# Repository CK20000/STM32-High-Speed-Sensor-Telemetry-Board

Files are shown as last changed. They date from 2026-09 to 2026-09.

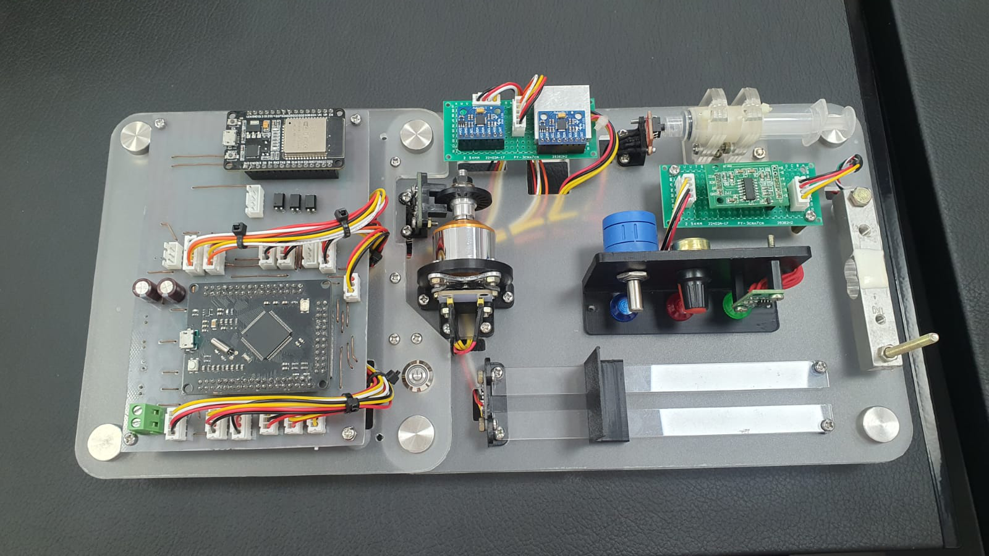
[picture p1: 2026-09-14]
hardware/images/WhatsApp Image 2026-08-07 at 17.46.26.jpeg

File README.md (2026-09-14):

# High-Speed Sensor Telemetry & Observer System Validation Board




[]()

## Project Overview
This repository contains the full hardware, firmware, and software stack for a custom sensor data acquisition board designed around the STM32F407VGT microcontroller. The system is engineered to capture, process, and stream multi-sensor data to validate a high-speed observer system framework. 

The architecture bridges custom PCB design, non-blocking C++ embedded firmware, and a modular Python dashboard to provide real-time telemetry, enabling precise tracking of stable motor rotation and load variables at high velocities.

WhatsApp Image 2026-08-07 at 17 46 26

---

## System Architecture

### 1. Hardware Integration (`/hardware`)
The custom-designed PCB acts as the central node for sensor fusion and motor state estimation. The board integrates the following components:
*   **MCU:** STM32F407VGT (ARM Cortex-M4).
*   **IMU:** MPU6050 (6-axis accelerometer and gyroscope) for inertial tracking.
*   **Magnetometer:** HMC5883L for heading reference.
*   **Time-of-Flight:** VL53L0X for precise distance measurements.
*   **Mechanical Sensors:** Direct interfaces for load cells and quadrature/optical encoders to track torque and rotation.
*   **Design Files:** KiCAD schematics, BOM, and mechanical CAD models are included.

### 2. Embedded Firmware (`/firmware`)
Written in C++, the firmware focuses on deterministic execution and high-speed data throughput:
*   **Non-Blocking I/O:** Ensures the sensor polling loop is not bottlenecked by communication delays.
*   **Telemetry Pipeline:** Constructs and streams an 84-byte binary payload containing timestamped sensor data and state variables.
*   **Virtual COM Port (VCP):** Utilizes USB CDC to achieve a stable 200Hz data transmission rate to the host PC. 

### 3. Telemetry Dashboard (`/software`)
A custom graphical interface developed in Python (PySide/PyQt) to visualize the observer system's performance in real-time.
*   **Serial Parsing (`comms.py`):** Efficiently unpacks the 84-byte binary stream at 200Hz.
*   **Real-Time Visualization (`gauges.py` / `ui/`):** Dynamic plotting of motor rotation, current readings, IMU data, and load metrics.
*   **Architecture:** Highly modular layout utilizing custom `.qss` stylesheets for a clean, industrial UI.

---

## Getting Started

### Prerequisites
*   **Hardware:** STM32 ST-LINK Utility or OpenOCD.
*   **Firmware:** ARM GCC Toolchain and CMake (or your preferred STM32 IDE like STM32CubeIDE).
*   **Software:** Python 3.8+ with `pyserial`, `PySide6` (or `PyQt6`), and `pyqtgraph`.

### Installation & Execution
1.  **Clone the Repository:**
    ```bash
    git clone [https://github.com/yourusername/stm32-telemetry-board.git](https://github.com/yourusername/stm32-telemetry-board.git)
    cd stm32-telemetry-board
    ```
2.  **Flash the Firmware:** 
    Compile the C++ source in the `/firmware` directory and flash the STM32F407 via ST-LINK.
3.  **Launch the Dashboard:**
    ```bash
    cd software
    pip install -r requirements.txt
    python main.py
    ```

---

## Current Development Status
*   [x] Custom PCB schematic and layout finalized.
*   [x] Virtual COM port pipeline validated (84-byte payload @ 200Hz).
*   [x] Python GUI rendering stable high-speed sensor plots.
*   [ ] Full observer system implementation in firmware (In Progress).

---

## License
This project is licensed under the MIT License - see the [LICENSE](LICENSE) file for details.

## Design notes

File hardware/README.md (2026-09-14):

Contains the KiCAD schematic, PCB layouts, component bill of materials, and mechanical CAD files for the sensor board.

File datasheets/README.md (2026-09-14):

Reference datasheets and documentation for components used on the board
(e.g. MPU6050, HMC5883L, VL53L0X, and other peripherals).

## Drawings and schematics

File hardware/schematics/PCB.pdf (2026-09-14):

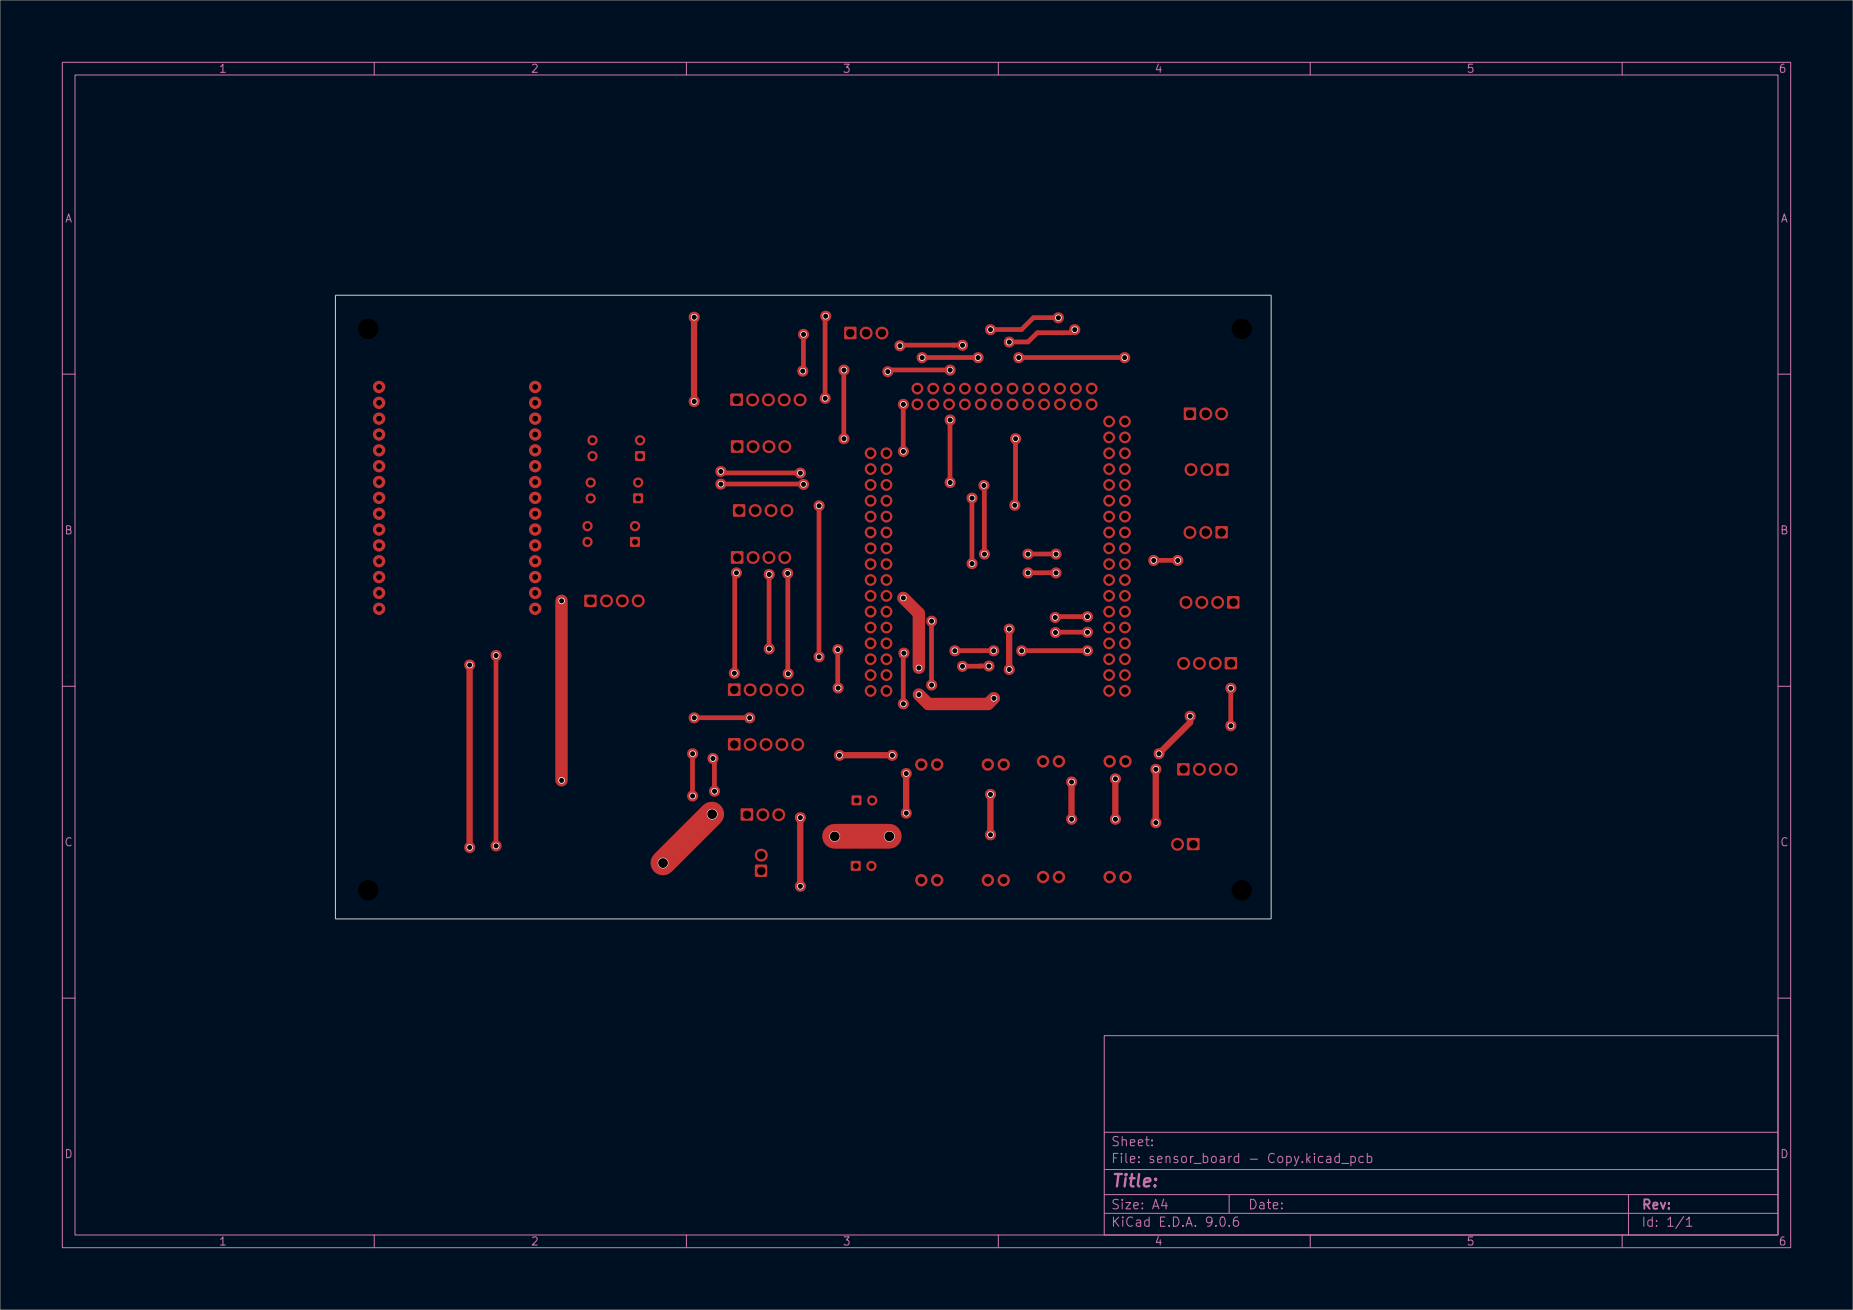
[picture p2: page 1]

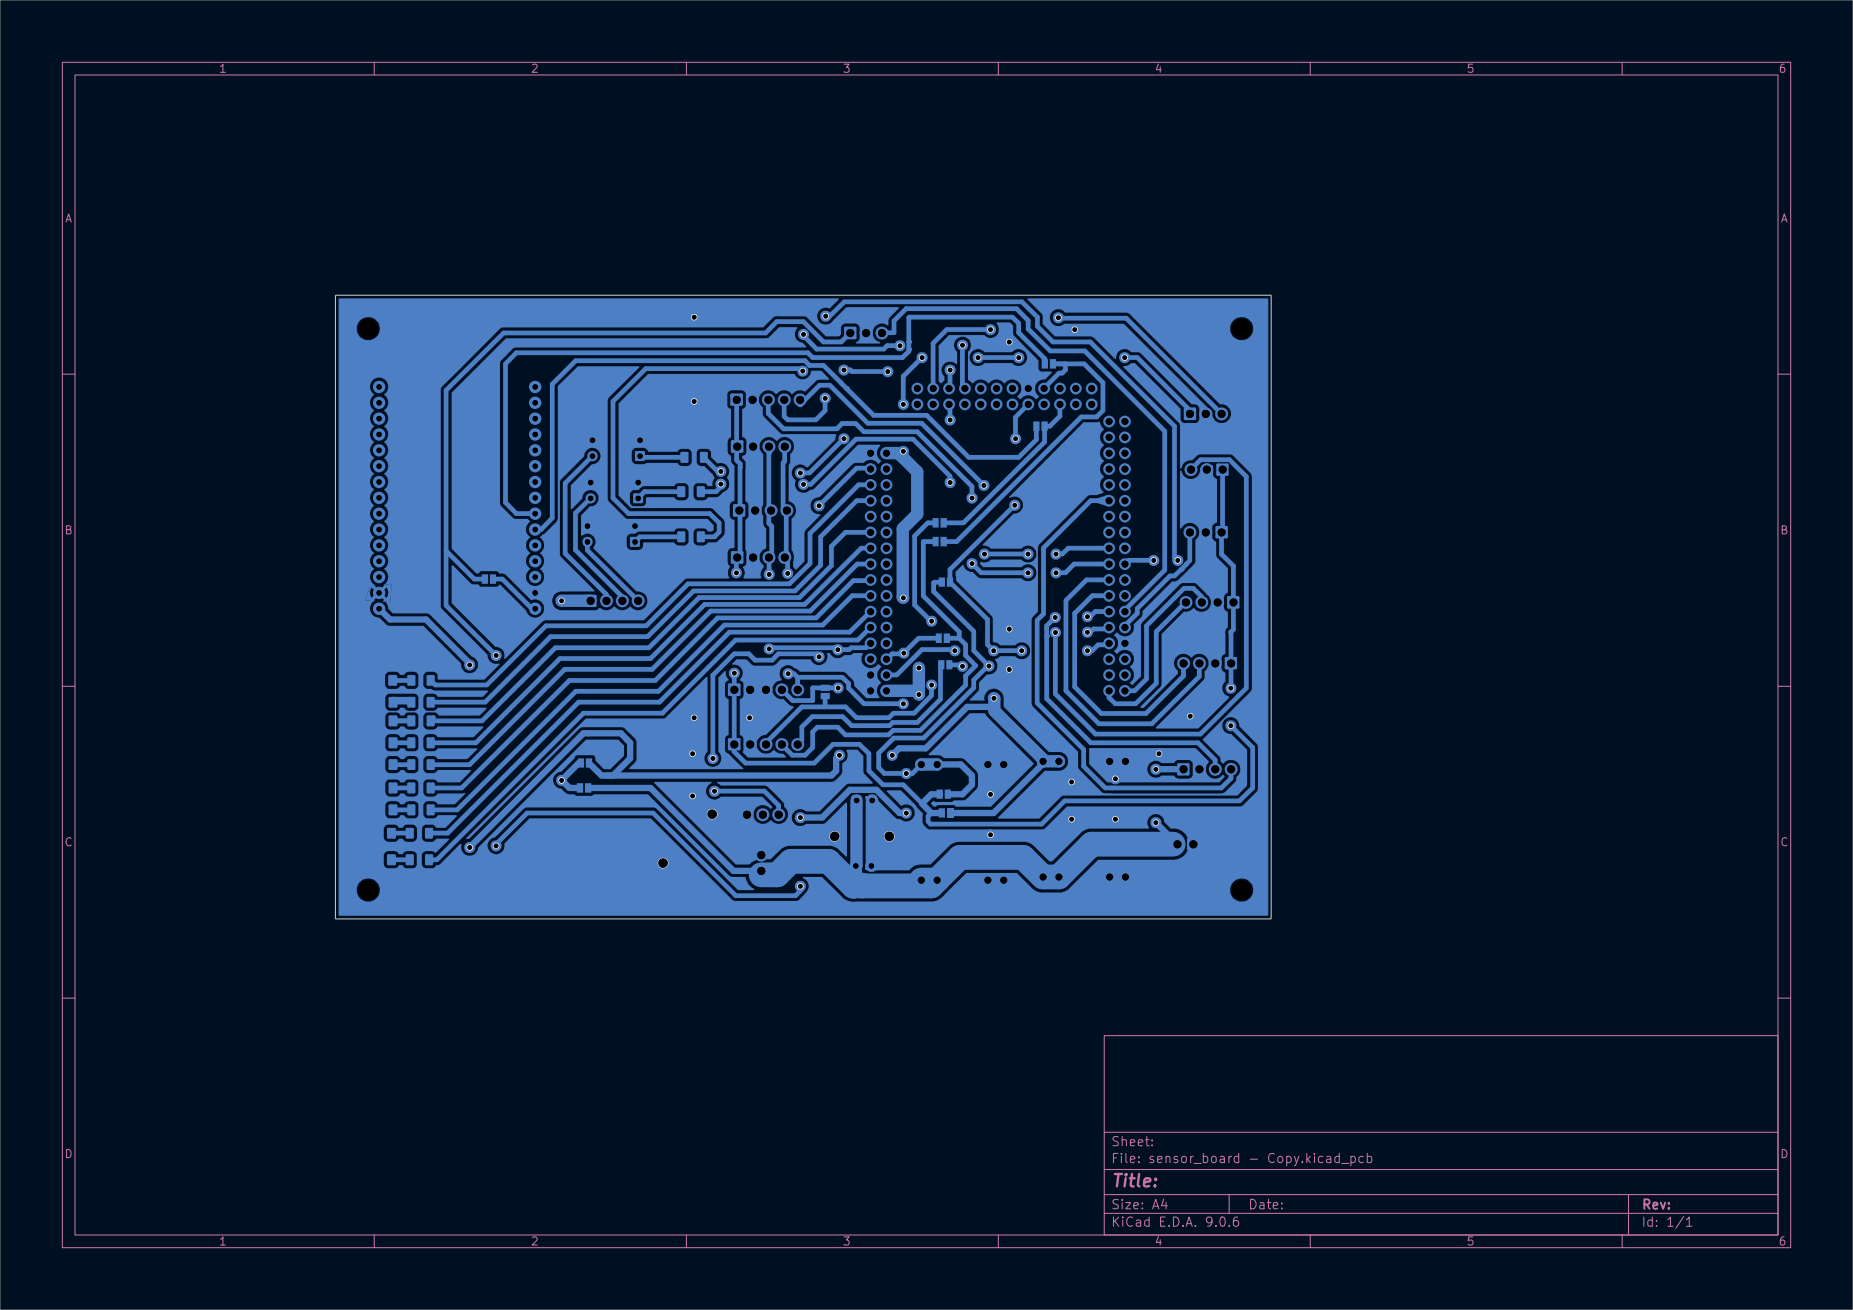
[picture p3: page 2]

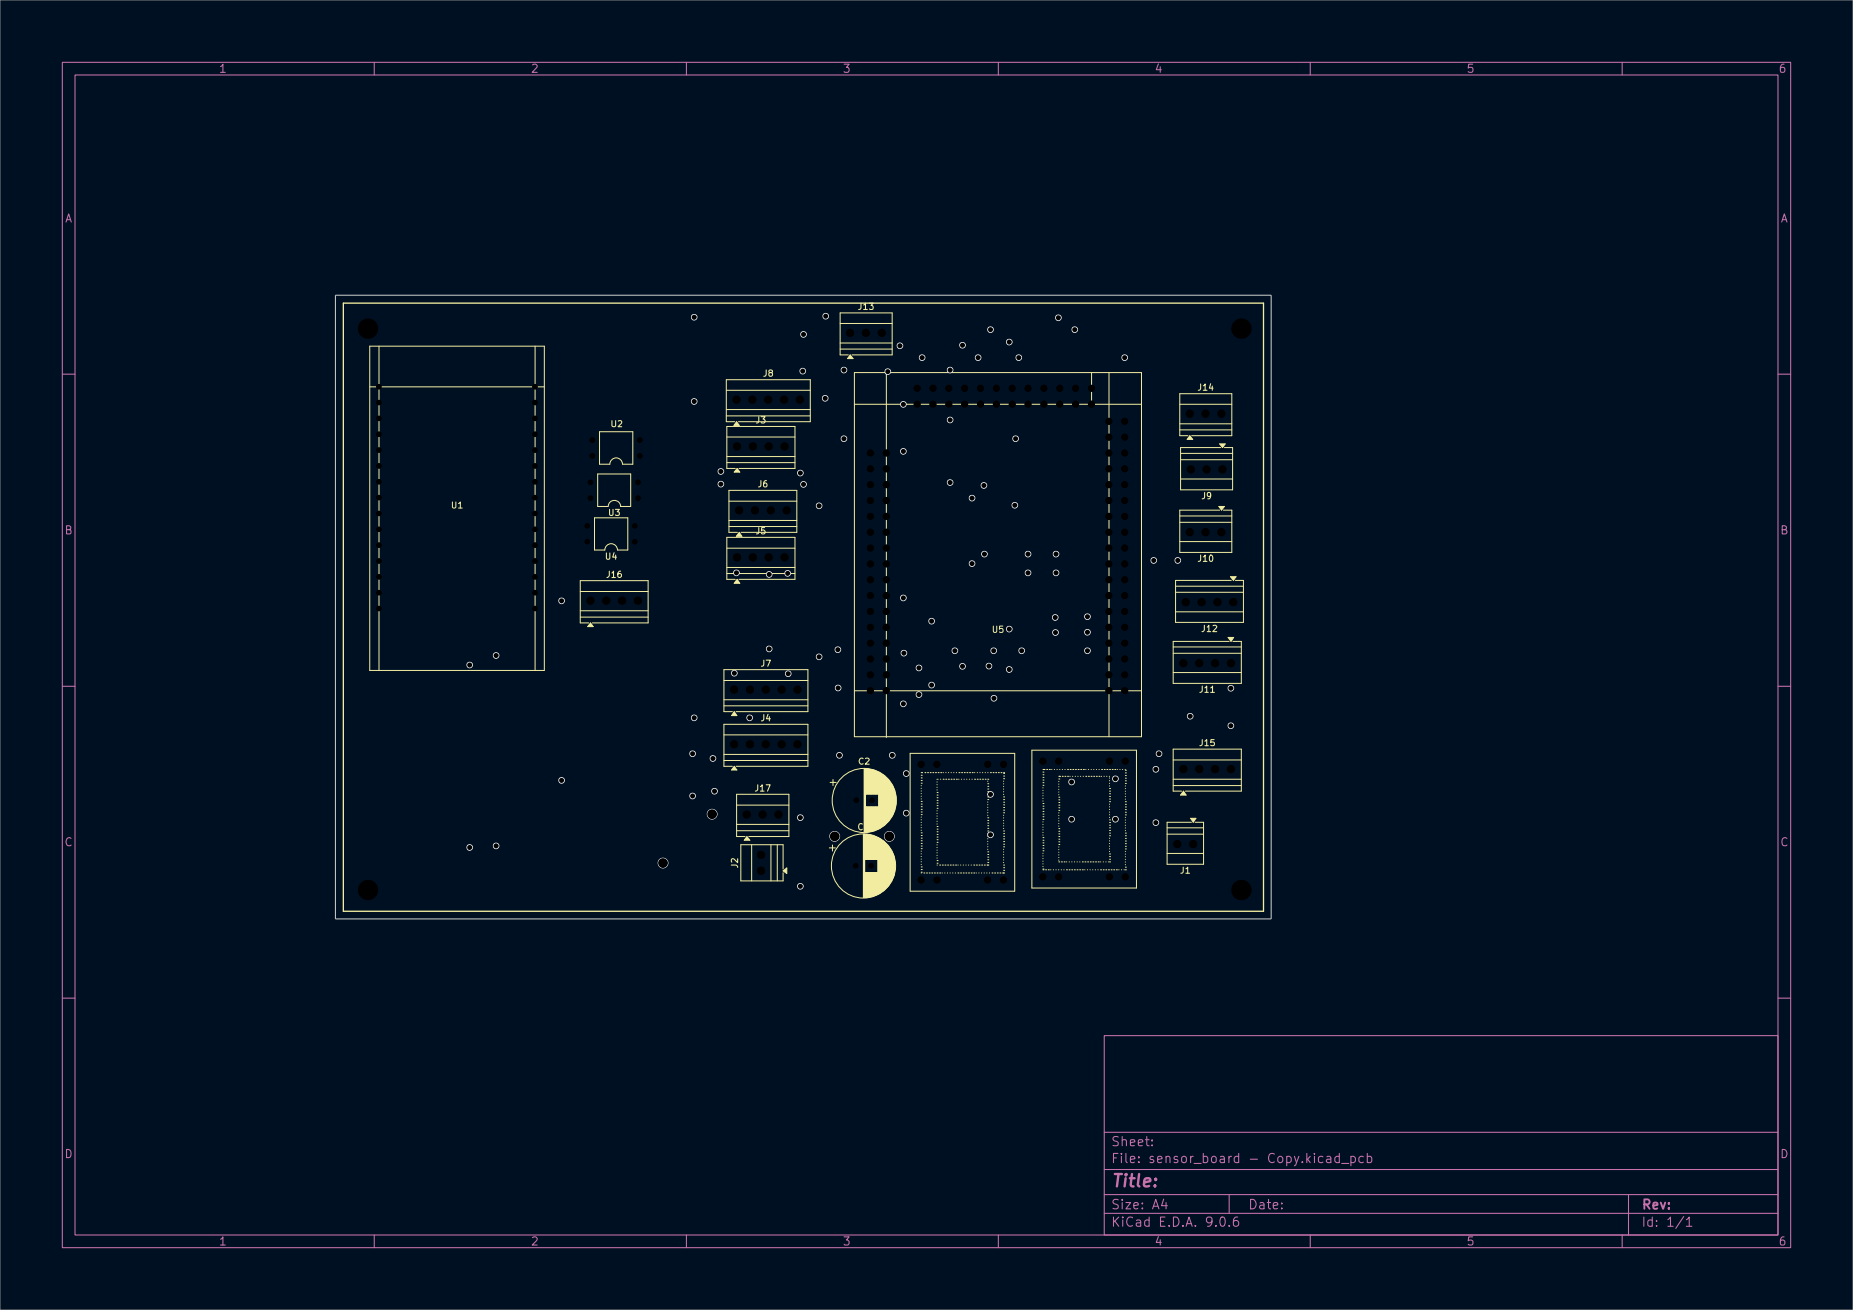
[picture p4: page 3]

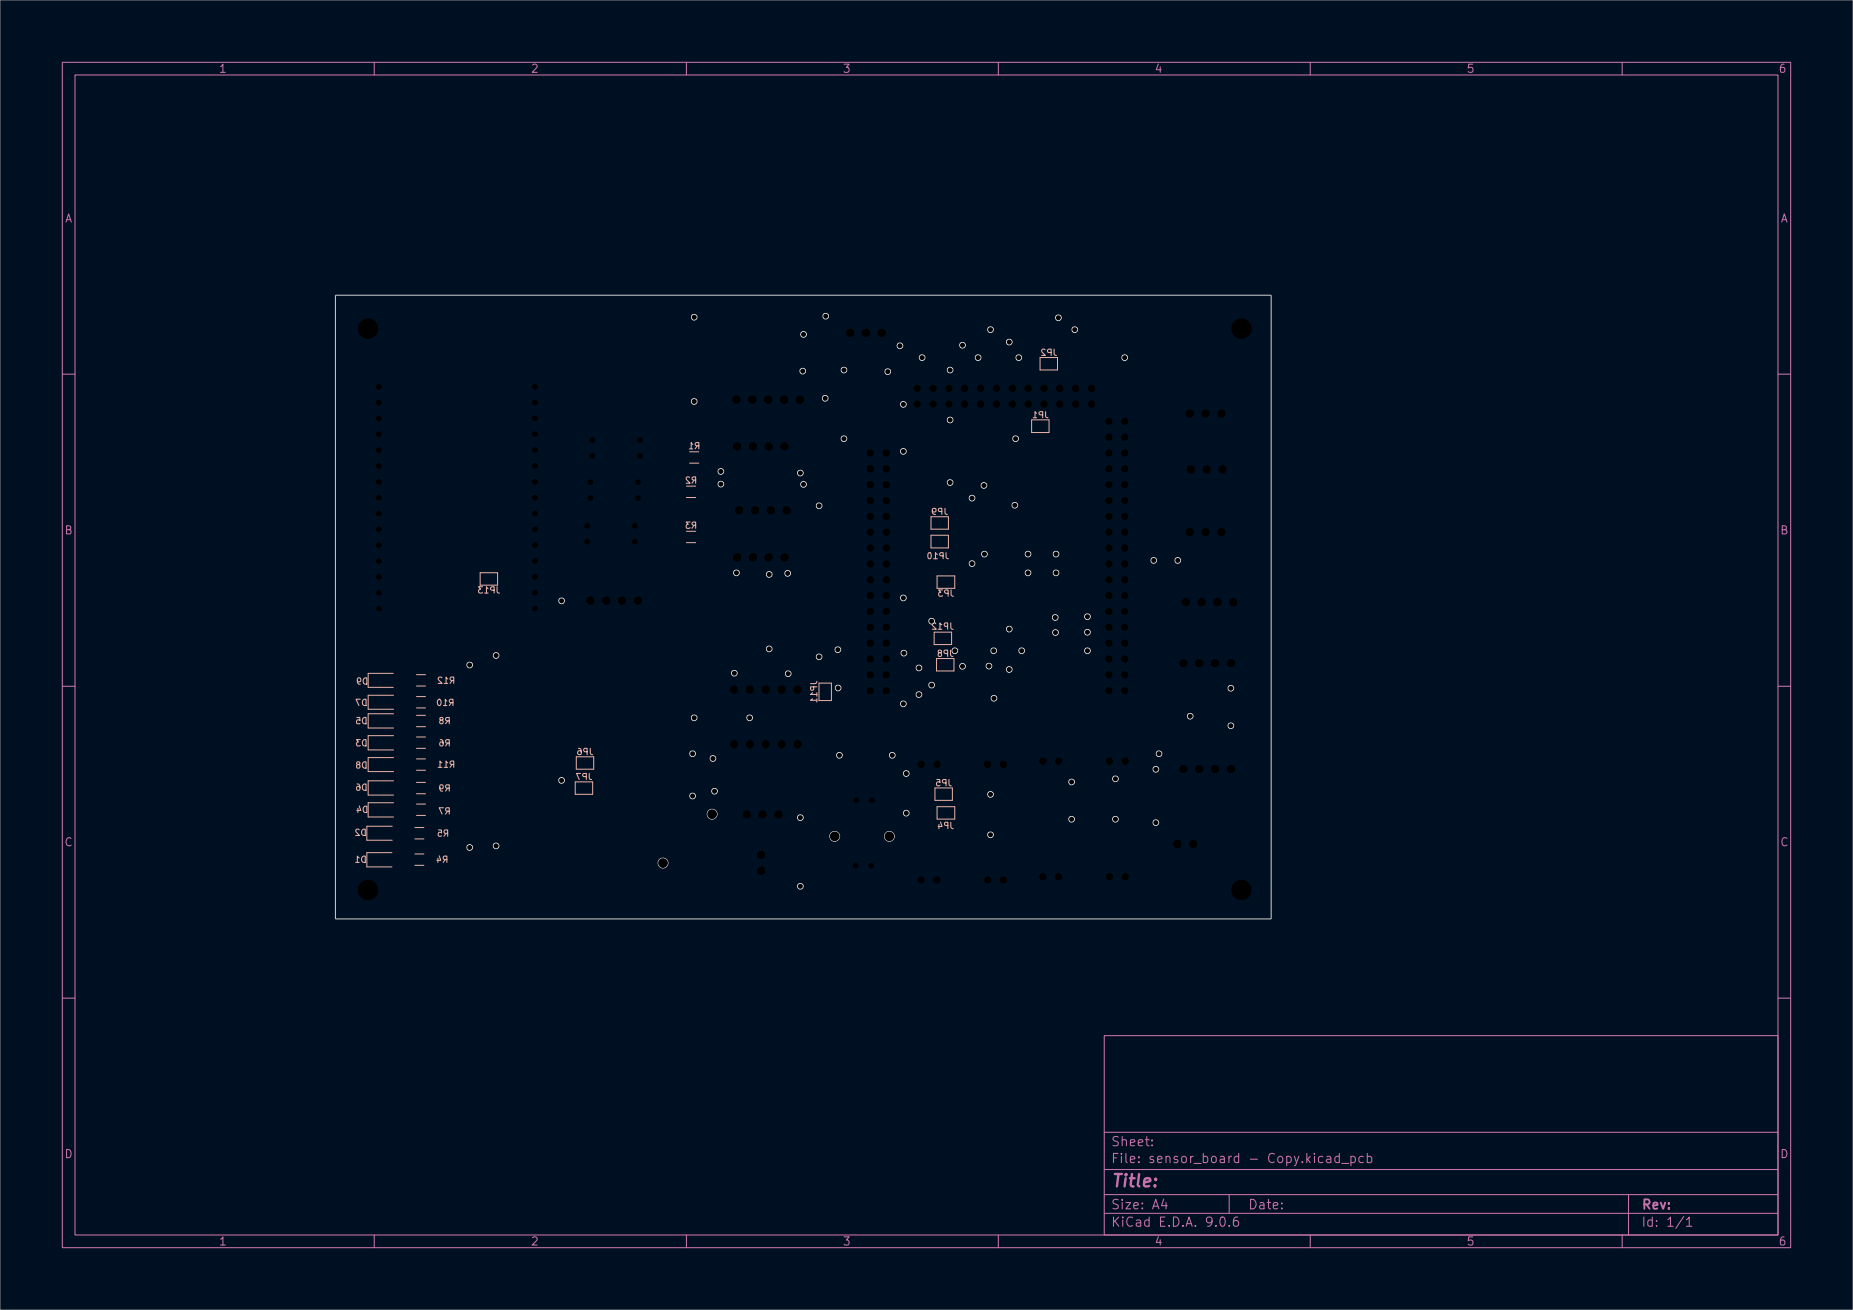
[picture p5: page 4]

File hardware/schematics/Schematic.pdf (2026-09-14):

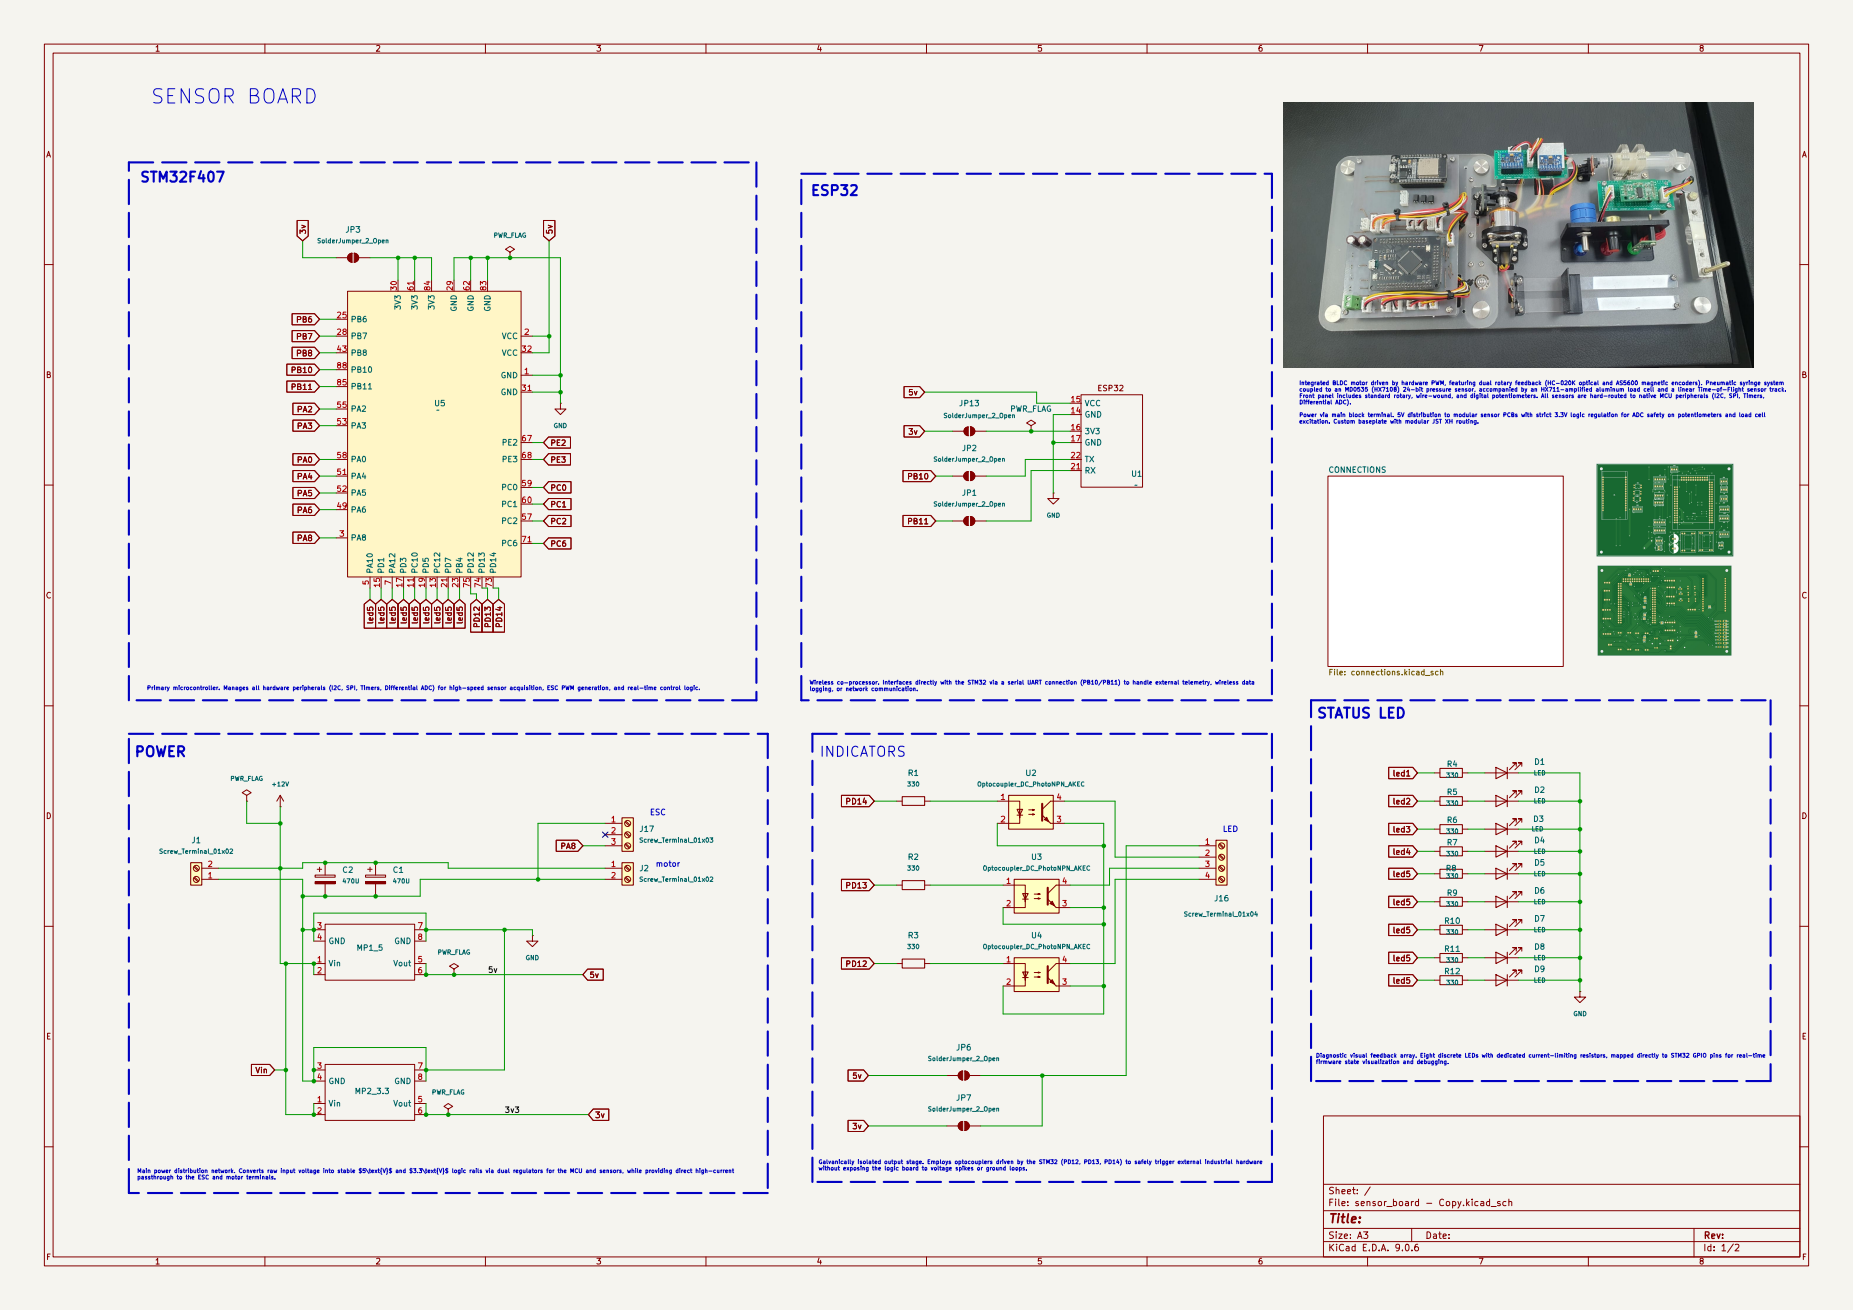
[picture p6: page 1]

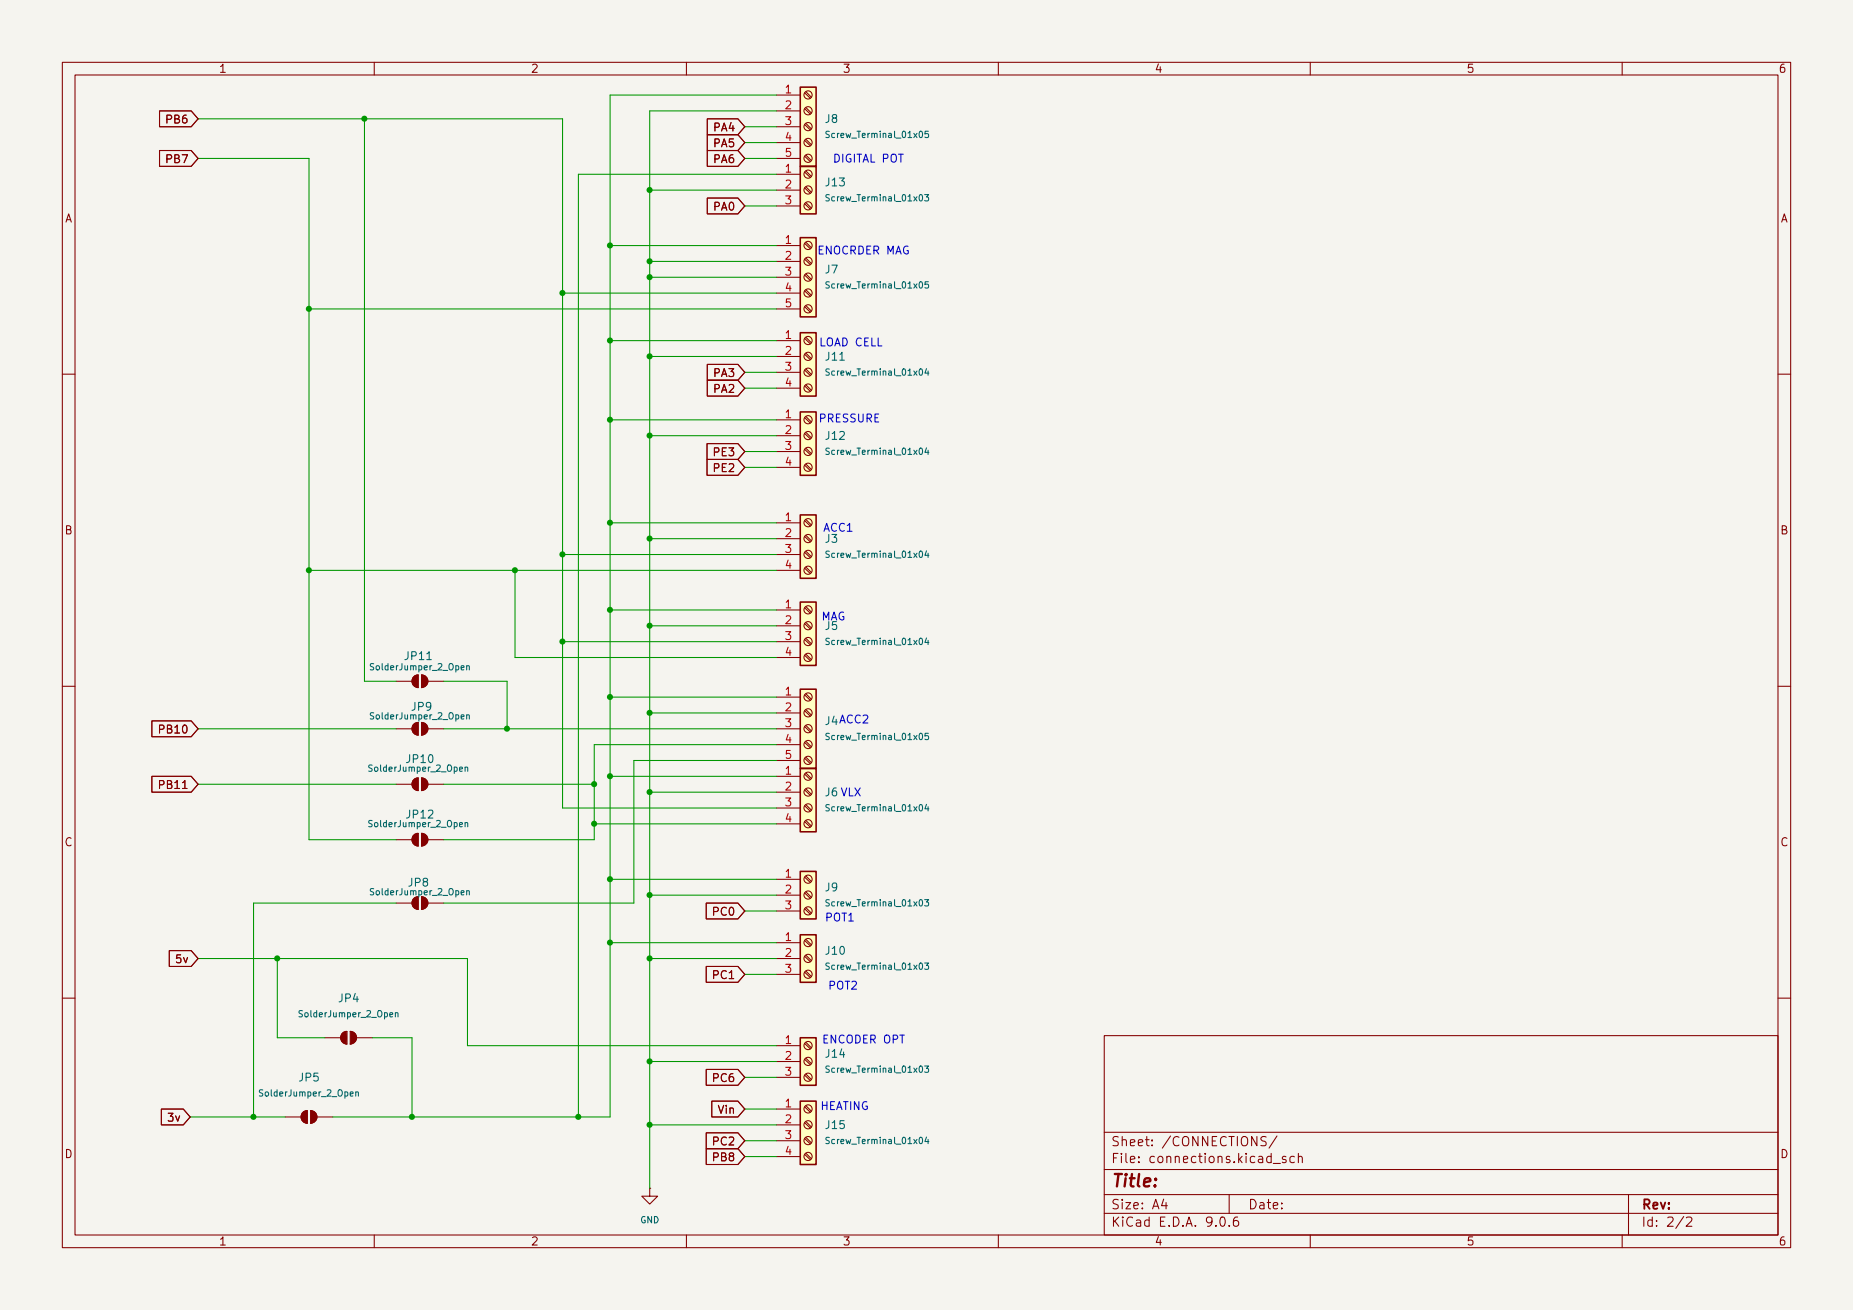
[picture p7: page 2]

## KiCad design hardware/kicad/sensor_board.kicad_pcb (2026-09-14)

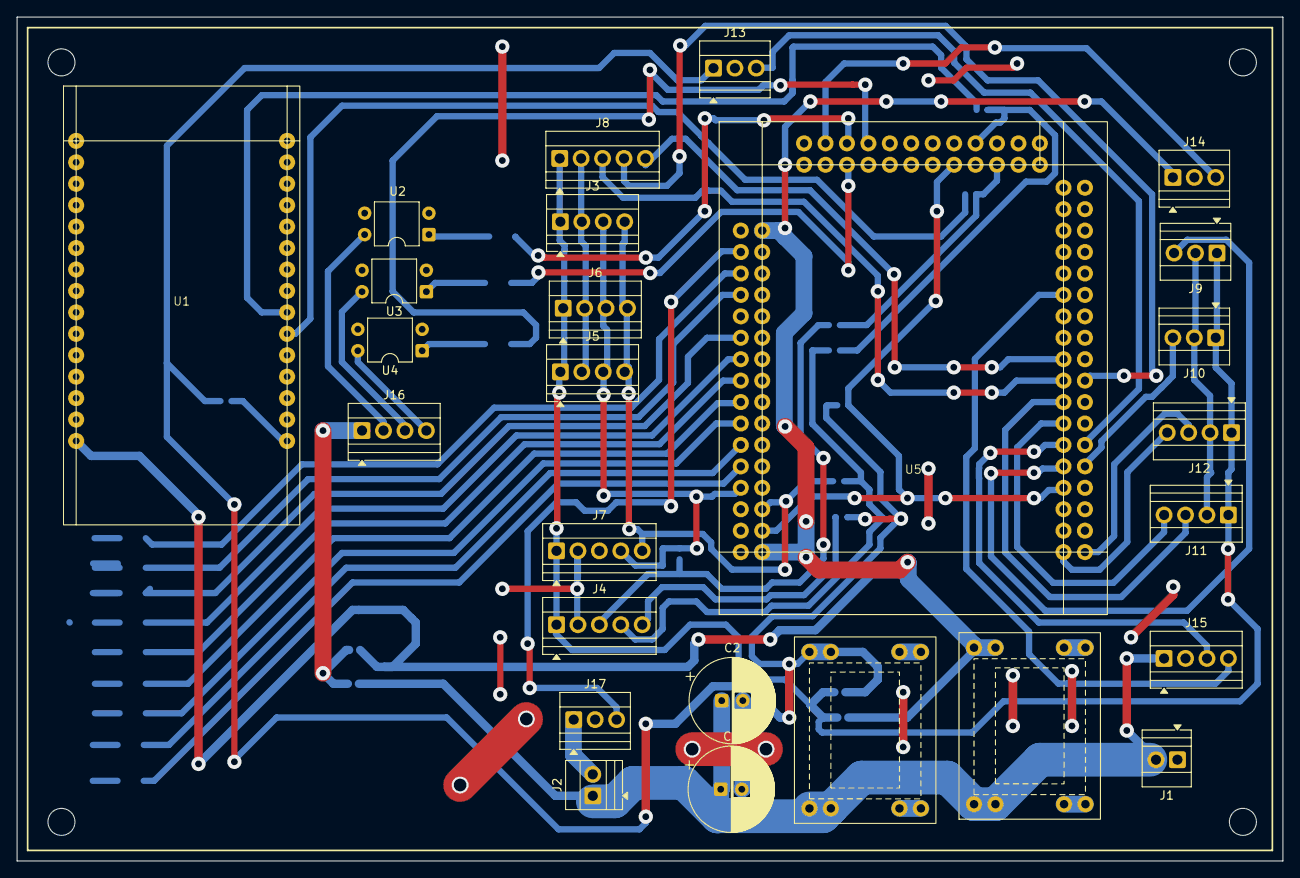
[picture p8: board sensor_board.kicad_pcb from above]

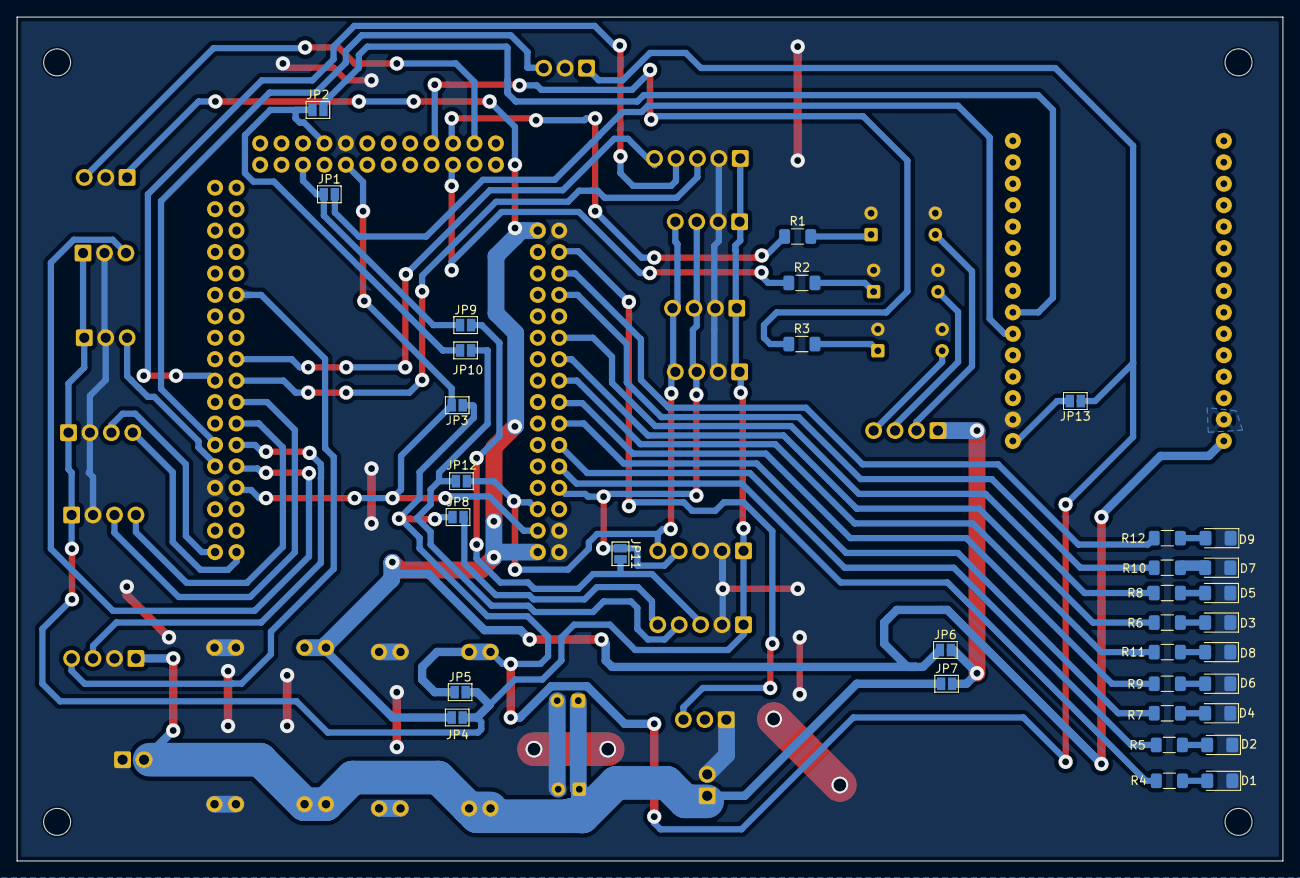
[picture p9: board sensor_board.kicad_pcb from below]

Board: 2 copper layers, 150.0 x 100.0 mm, 60 parts (34 on the bottom side), 58 nets.

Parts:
C1, C2: 470U; CP_Radial_D10.0mm_P2.50mm
D1, D2, D3, D4, D5, D6, D7, D8, D9: LED; LED_1206_3216Metric_Pad1.42x1.75mm_HandSolder
J1, J2: Screw_Terminal_01x02; TerminalBlock_Xinya_XY308-2.54-2P_1x02_P2.54mm_Horizontal
J3, J5, J6, J11, J12, J15, J16: Screw_Terminal_01x04; TerminalBlock_Xinya_XY308-2.54-4P_1x04_P2.54mm_Horizontal
J4, J7, J8: Screw_Terminal_01x05; TerminalBlock_Xinya_XY308-2.54-5P_1x05_P2.54mm_Horizontal
J9, J10, J13, J14, J17: Screw_Terminal_01x03; TerminalBlock_Xinya_XY308-2.54-3P_1x03_P2.54mm_Horizontal
JP1, JP2, JP3, JP4, JP5, JP6, JP7, JP8, JP9, JP10, JP11, JP12, JP13: SolderJumper_2_Open; SolderJumper-2_P1.3mm_Open_Pad1.0x1.5mm
MP1_5, MP2_3.3: MP1584
R1, R2, R3, R4, R5, R6, R7, R8, R9, R10, R11, R12: 330; R_1206_3216Metric_Pad1.30x1.75mm_HandSolder
U1: ESP32_WROOM_32
U2, U3, U4: Optocoupler_DC_PhotoNPN_AKEC; DIP-4_W7.62mm
U5: STM32_F407VGT

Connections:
+12V: C1.1, C2.1, J1.2, J2.1, J15.1, JP7.1 (A), MP1_5.1 (Vin), MP1_5.2, MP2_3.3.1 (Vin), MP2_3.3.2
/3v3: J13.1, JP3.1 (A), JP5.1 (A), JP8.1 (A), JP13.1 (A), MP2_3.3.5 (Vout), MP2_3.3.6
/5v: J14.1, JP4.1 (A), JP6.1 (A), MP1_5.5 (Vout), MP1_5.6, U1.15 (VCC), U5.2 (VCC), U5.32 (VCC)
GND: C1.2, C2.2, D1.1 (K), D2.1 (K), D3.1 (K), D4.1 (K), D5.1 (K), D6.1 (K), D7.1 (K), D8.1 (K), D9.1 (K), J1.1, J2.2, J3.2, J4.2, J5.2, J6.2, J7.2, J7.3, J8.2, J9.2, J10.2, J11.2, J12.2, J13.2, J14.2, J15.2, J17.1, MP1_5.3, MP1_5.4 (GND), MP1_5.7, MP1_5.8 (GND), MP2_3.3.3, MP2_3.3.4 (GND), MP2_3.3.7, MP2_3.3.8 (GND), U1.14 (GND), U1.17 (GND), U2.2, U2.3, U3.2, U3.3, U4.2, U4.3, U5.1 (GND), U5.29 (GND), U5.31 (GND), U5.62 (GND), U5.83 (GND)
unnamed: D1.2 (A), R4.2
unnamed: D2.2 (A), R5.2
unnamed: D3.2 (A), R6.2
unnamed: D4.2 (A), R7.2
unnamed: D5.2 (A), R8.2
unnamed: D6.2 (A), R9.2
unnamed: D7.2 (A), R10.2
unnamed: D8.2 (A), R11.2
unnamed: D9.2 (A), R12.2
unnamed: J3.3, J5.3, J6.3, J7.4, JP11.1 (A), U5.25 (PB6)
unnamed: J3.4, J5.4, J6.4, J7.5, JP12.1 (A), U5.28 (PB7)
unnamed: J4.3, JP9.2 (B), JP11.2 (B)
unnamed: J4.4, JP10.2 (B), JP12.2 (B)
unnamed: J4.5, JP8.2 (B)
unnamed: J8.3, U5.51 (PA4)
unnamed: J8.4, U5.52 (PA5)
unnamed: J8.5, U5.49 (PA6)
unnamed: J9.3, U5.59 (PC0)
unnamed: J3.1, J4.1, J5.1, J6.1, J7.1, J8.1, J9.1, J10.1, J11.1, J12.1, JP4.2 (B), JP5.2 (B)
unnamed: J10.3, U5.60 (PC1)
unnamed: J11.3, U5.53 (PA3)
unnamed: J11.4, U5.55 (PA2)
unnamed: J12.3, U5.68 (PE3)
unnamed: J12.4, U5.67 (PE2)
unnamed: J13.3, U5.58 (PA0)
unnamed: J14.3, U5.71 (PC6)
unnamed: J15.3, U5.57 (PC2)
unnamed: J15.4, U5.43 (PB8)
unnamed: J16.1, JP6.2 (B), JP7.2 (B)
unnamed: J16.2, U2.4
unnamed: J16.3, U3.4
unnamed: J16.4, U4.4
unnamed: J17.3, U5.3 (PA8)
unnamed: JP1.1 (A), JP9.1 (A), U5.88 (PB10)
unnamed: JP1.2 (B), U1.21 (RX)
unnamed: JP2.2 (B), U1.22 (TX)
unnamed: JP3.2 (B), U5.30 (3V3), U5.61 (3V3), U5.84 (3V3)
unnamed: JP2.1 (A), JP10.1 (A), U5.85 (PB11)
unnamed: JP13.2 (B), U1.16 (3V3)
unnamed: R1.2, U2.1
unnamed: R2.2, U3.1
unnamed: R3.2, U4.1
unnamed: R12.1, U5.5 (PA10)
unnamed: R10.1, U5.7 (PA12)
unnamed: R4.1, U5.23 (PB4)
unnamed: R8.1, U5.11 (PC10)
unnamed: R6.1, U5.13 (PC12)
unnamed: R11.1, U5.15 (PD1)
unnamed: R9.1, U5.17 (PD3)
unnamed: R7.1, U5.19 (PD5)
unnamed: R5.1, U5.21 (PD7)
unnamed: R3.1, U5.75 (PD12)
unnamed: R2.1, U5.74 (PD13)
unnamed: R1.1, U5.73 (PD14)

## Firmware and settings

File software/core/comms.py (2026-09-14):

# core/comms.py
import serial
import serial.tools.list_ports  # <--- CRITICAL FOR SMART DETECTION
import struct
import time
from PySide6.QtCore import QThread, Signal


class STM32DataBridge(QThread):
    # --- ADDED A NEW CONNECTION STATUS SIGNAL ---
    connection_status = Signal(str, bool)  # e.g. ("COM5", True) or ("SEARCHING...", False)

    sys_data = Signal(float, float)
    acc1_data = Signal(float, float, float)
    acc2_data = Signal(float, float, float)
    vlx_data = Signal(float)
    enc_data = Signal(float, float)
    ldc_press_data = Signal(float, float)
    pot_data = Signal(int, int, int)
    mag_data = Signal(float, float, float)

    def __init__(self, baudrate=500000):  # Notice: Removed the hardcoded 'port' arg!
        super().__init__()
        self.baudrate = baudrate
        self.is_running = False
        self.serial_conn = None

        self.packet_format = '<4s ff HH fff fff f ff ff iii fff'
        self.packet_size = struct.calcsize(self.packet_format)

    def find_stm32_port(self):
        """Scans the hardware registry for STM32 devices without opening ports"""
        ports = serial.tools.list_ports.comports()
        for p in ports:
            # 0x0483 is STMicroelectronics. 0x5740 is their standard Virtual COM Port PID.
            if p.vid == 0x0483:
                return p.device
            # Fallback: Check if the device description explicitly says "STM32"
            if "STM" in (p.description or ""):
                return p.device
        return None

    def run(self):
        self.is_running = True
        sync_pattern = b'\xAA\xBB\xCC\xDD'
        buffer = b''

        while self.is_running:
            # ==========================================
            # STATE 1: SMART AUTO-CONNECT (0% CPU LOAD)
            # ==========================================
            if self.serial_conn is None or not self.serial_conn.is_open:
                self.connection_status.emit("SEARCHING FOR STM32...", False)

                port_name = self.find_stm32_port()

                if port_name:
                    try:
                        self.serial_conn = serial.Serial(port_name, self.baudrate, timeout=0)
                        self.connection_status.emit(f"STM32 CONNECTED // {port_name}", True)
                        buffer = b''  # Clear any old garbage data
                    except Exception as e:
                        time.sleep(1)  # Port found but locked by Windows, wait and retry
                        continue
                else:
                    time.sleep(1)  # SLEEP FOR 1 SECOND. Do not flood the CPU!
                    continue

            # ==========================================
            # STATE 2: HIGH-SPEED TELEMETRY LOOP
            # ==========================================
            try:
                if self.serial_conn.in_waiting > 0:
                    buffer += self.serial_conn.read(self.serial_conn.in_waiting)

                    while True:
                        sync_idx = buffer.find(sync_pattern)

                        if sync_idx == -1:
                            buffer = buffer[-3:] if len(buffer) >= 3 else buffer
                            break

                        if sync_idx > 0:
                            buffer = buffer[sync_idx:]

                        if len(buffer) < self.packet_size:
                            break

                        frame = buffer[:self.packet_size]
                        buffer = buffer[self.packet_size:]

                        parsed = struct.unpack(self.packet_format, frame)

                        self.sys_data.emit(parsed[1], parsed[2])
                        self.acc1_data.emit(parsed[5], parsed[6], parsed[7])
                        self.acc2_data.emit(parsed[8], parsed[9], parsed[10])
                        self.vlx_data.emit(parsed[11])
                        self.enc_data.emit(parsed[12], parsed[13])
                        self.ldc_press_data.emit(parsed[14], parsed[15])
                        self.pot_data.emit(parsed[16], parsed[17], parsed[18])
                        self.mag_data.emit(parsed[19], parsed[20], parsed[21])
                else:
                    time.sleep(0.005) # <--- CHANGE THIS FROM 0.001 TO 0.005

            except serial.SerialException:
                # CABLE UNPLUGGED! Catch the crash safely and return to STATE 1
                self.serial_conn.close()
                self.serial_conn = None

    def send_gui_state(self, master_on, active_mask):
        if self.serial_conn and self.serial_conn.is_open:
            try:
                cmd = struct.pack('<BBBB', 0xAA, 0xBB, int(master_on), active_mask)
                self.serial_conn.write(cmd)
            except serial.SerialException:
                pass  # Ignore write errors if cable is yanked mid-click

    def stop(self):
        self.is_running = False
        self.wait()

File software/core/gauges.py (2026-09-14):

# Create new file: core/gauges.py
import math
from PySide6.QtWidgets import QWidget
from PySide6.QtCore import Qt, QPointF, QRectF
from PySide6.QtGui import QPainter, QColor, QPen, QPolygonF, QRadialGradient


class GX360Dial(QWidget):
    def __init__(self, dual_mode=False, color1="#00ffcc", color2="#fa1e4e"):
        super().__init__()
        self.setMinimumSize(250, 250)
        self.dual_mode = dual_mode
        self.val1 = 0  # Cyan hand (Optical)
        self.val2 = 0  # Neon Red hand (Magnetic)
        self.color1_hex = color1
        self.color2_hex = color2
        self.val_label_text = "DEG"

    def update_values(self, v1, v2=0):
        self.val1 = v1 % 360
        self.val2 = v2 % 360
        self.update()  # Triggers a GPU repaint

    def paintEvent(self, event):
        painter = QPainter(self)
        painter.setRenderHint(QPainter.Antialiasing)

        # Center coordinates and radius
        cx = self.width() / 2
        cy = self.height() / 2
        radius = min(cx, cy) - 20

        # 1. Draw the Background and Main Ring
        # Use a radial gradient for depth
        gradient = QRadialGradient(cx, cy, radius)
        gradient.setColorAt(0, QColor("#1a1a24"))
        gradient.setColorAt(0.9, QColor("#121217"))
        painter.setBrush(gradient)
        painter.setPen(QPen(QColor("#2a2a35"), 4))
        painter.drawEllipse(QPointF(cx, cy), radius, radius)

        # 2. Draw Ticks
        painter.setPen(QPen(QColor("#555566"), 1.5))
        for deg in range(0, 360, 10):
            rad = math.radians(deg - 90)
            inner_r = radius - 15
            outer_r = radius
            if deg % 90 == 0:
                inner_r = radius - 25
                painter.setPen(QPen(QColor("#ffffff"), 2))
            else:
                painter.setPen(QPen(QColor("#555566"), 1.5))

            x1 = cx + inner_r * math.cos(rad)
            y1 = cy + inner_r * math.sin(rad)
            x2 = cx + outer_r * math.cos(rad)
            y2 = cy + outer_r * math.sin(rad)
            painter.drawLine(QPointF(x1, y1), QPointF(x2, y2))

        # 3. Draw Hands (Needles)
        # Helper function to create the hand polygon using trig
        def create_hand_poly(val, length_factor, width_factor):
            rad = math.radians(val - 90)
            length = radius * length_factor
            width = 12 * width_factor

            p_tip = QPointF(cx + length * math.cos(rad), cy + length * math.sin(rad))
            p_left = QPointF(cx + width * math.cos(rad - math.pi / 2), cy + width * math.sin(rad - math.pi / 2))
            p_right = QPointF(cx + width * math.cos(rad + math.pi / 2), cy + width * math.sin(rad + math.pi / 2))

            #poly = QPolygonF([cx, cy, p_left, p_tip, p_right])
            poly = QPolygonF([QPointF(cx, cy), p_left, p_tip, p_right])
            return poly

        # Draw Hand 1 (Cyan)
        hand1_poly = create_hand_poly(self.val1, 0.95, 1.0)
        painter.setBrush(QColor(self.color1_hex))
        painter.setPen(Qt.NoPen)
        painter.drawPolygon(hand1_poly)

        # Draw Hand 2 (Red) if in Dual Mode
        if self.dual_mode:
            hand2_poly = create_hand_poly(self.val2, 0.8, 1.2)
            painter.setBrush(QColor(self.color2_hex))
            painter.drawPolygon(hand2_poly)

        # 4. Draw center pivot
        painter.setBrush(QColor("#ffffff"))
        painter.drawEllipse(QPointF(cx, cy), 12, 12)

        # 5. Draw Digital Display text
        painter.setPen(QColor("#ffffff"))
        painter.setFont(self.parent().font())  # Use application font
        display_text = f"{int(self.val1)}°"
        if self.dual_mode:
            display_text += f" // {int(self.val2)}°"
        painter.drawText(self.rect(), Qt.AlignBottom | Qt.AlignHCenter, display_text)


# --- THE NEW ARC GAUGE (For Tab 5 Potentiometers) ---
class GXArcGauge(QWidget):
    def __init__(self, color="#00ffcc", title="DATA", max_val=360):
        super().__init__()
        self.setMinimumSize(220, 220)
        self.val = 0
        self.max_val = max_val
        self.color_hex = color
        self.title = title

    def update_value(self, v):
        self.val = v
        self.update()  # Trigger GPU repaint

    def paintEvent(self, event):
        painter = QPainter(self)
        painter.setRenderHint(QPainter.Antialiasing)

        # Make it a perfect square in the center of the widget
        side = min(self.width(), self.height())
        rect = QRectF((self.width() - side) / 2 + 20, (self.height() - side) / 2 + 20, side - 40, side - 40)

        # 1. Background Dark Track
        pen_bg = QPen(QColor("#2a2a35"), 18, Qt.SolidLine, Qt.FlatCap)
        painter.setPen(pen_bg)
        # PySide Angles: 16th of a degree. Start bottom-left (225°), Span 270° clockwise (negative span)
        painter.drawArc(rect, 225 * 16, -270 * 16)

        # 2. Glowing Value Arc
        pen_val = QPen(QColor(self.color_hex), 18, Qt.SolidLine, Qt.FlatCap)
        painter.setPen(pen_val)

        # Calculate how much of the arc to fill based on the current value
        # Prevent division by zero or over-drawing
        safe_val = min(max(self.val, 0), self.max_val)
        span = int((-270 * (safe_val / self.max_val)) * 16)
        painter.drawArc(rect, 225 * 16, span)

        # 3. Main Number Display (Shifted slightly up)
        painter.setPen(QColor("#ffffff"))
        font = painter.font()
        font.setPointSize(36)
        font.setBold(True)
        painter.setFont(font)
        painter.drawText(self.rect().adjusted(0, -20, 0, 0), Qt.AlignCenter, f"{int(self.val)}")

        # 4. Title / Subtext (Shifted up to sit under the number)
        font.setPointSize(12)
        font.setBold(False)
        painter.setFont(font)
        painter.setPen(QColor("#8a8a93"))
        painter.drawText(self.rect().adjusted(0, 50, 0, 0), Qt.AlignCenter, self.title)
